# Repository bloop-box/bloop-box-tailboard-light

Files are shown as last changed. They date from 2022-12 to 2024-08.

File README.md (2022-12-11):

# Bloop Box Tailboard Light



Tailboard 3D Render

[Documentation](https://bloop-box.github.io/bloop-box-tailboard-light)

The board is designed using KiCAD 6 with production and assembly by JLCPCB in mind. All parts are selected to be
available from JLCPCB. At the time of writing as many parts as possible are used from their basic library.

- USB-C Power Input
- 5V only
- Two buttons connected to the Raspberry Pi, per default used for volume control
- Three LEDs 
  - One to show status of power supply
  - Two can be remote-controlled by Raspberry Pi through the Mainboard

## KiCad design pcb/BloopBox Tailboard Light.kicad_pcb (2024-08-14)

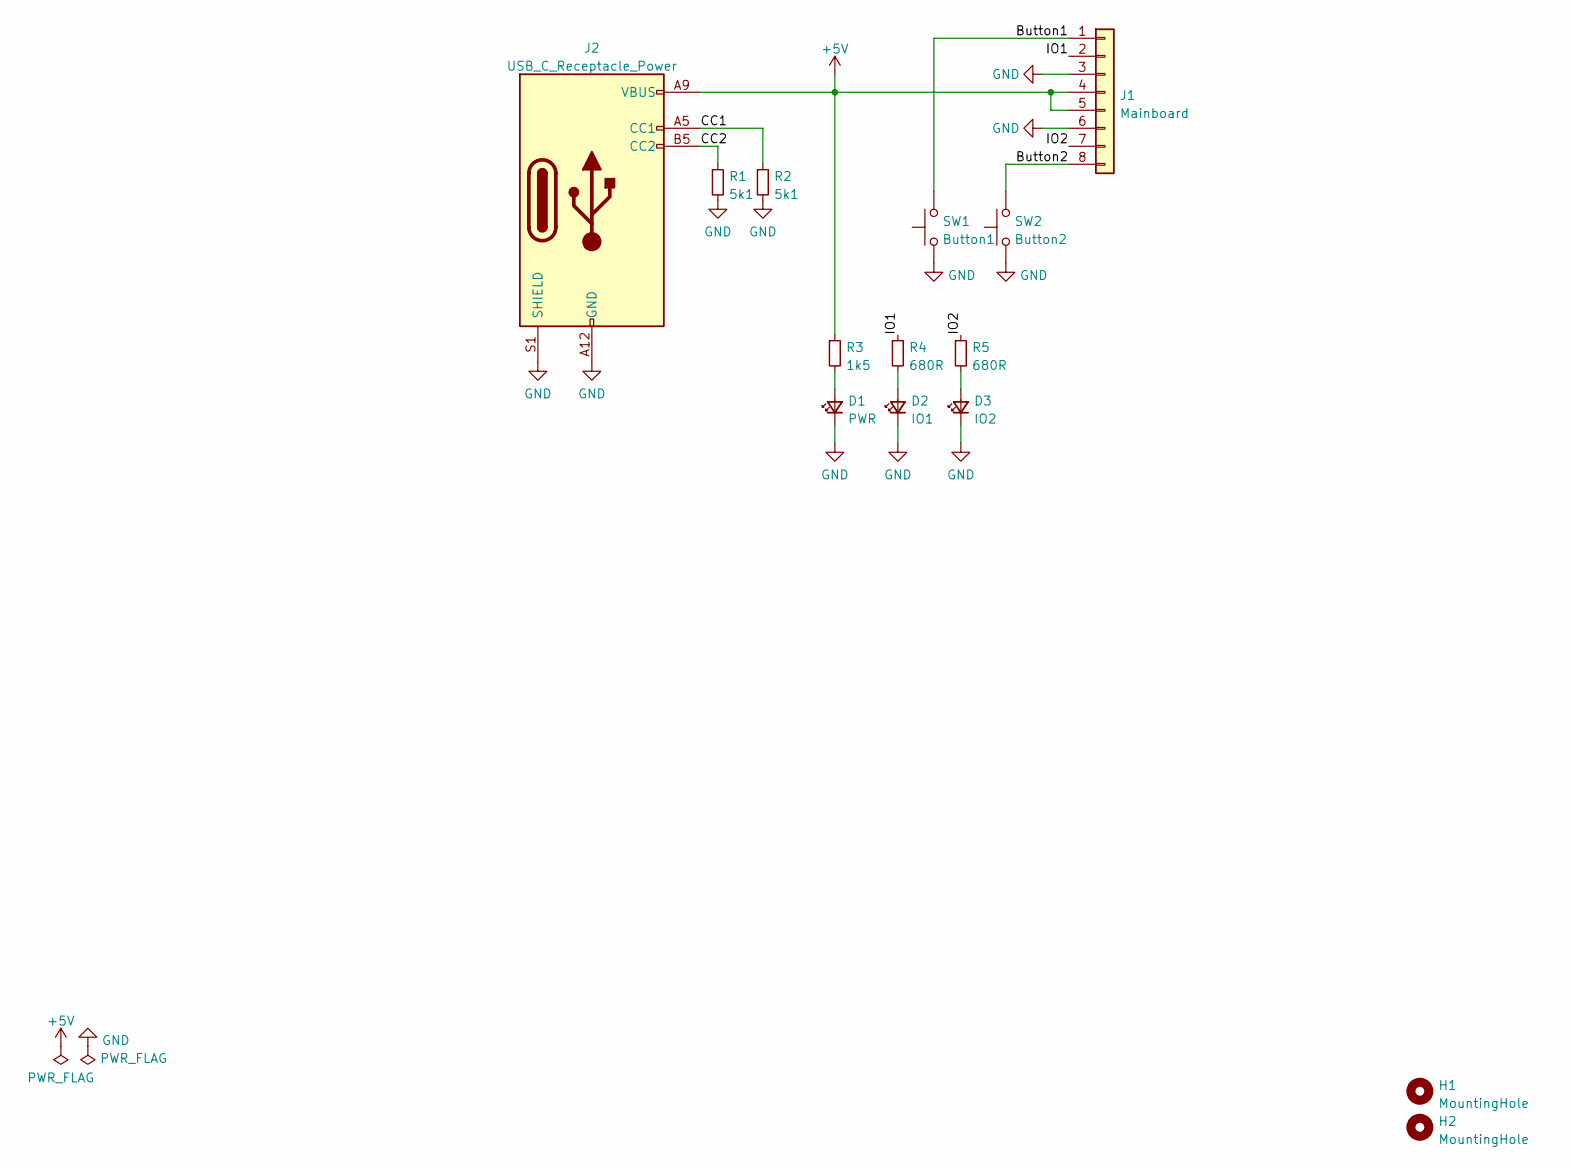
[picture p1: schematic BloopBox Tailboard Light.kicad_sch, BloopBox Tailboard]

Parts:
D1: PWR; LED_0603_1608Metric; LCSC C72038
D2: IO1; LED_0603_1608Metric; LCSC C72038
D3: IO2; LED_0603_1608Metric; LCSC C72038
H1, H2: MountingHole; MountingHole_3.2mm_M3
J1: Mainboard; JST_PH_S8B-PH-K_1x08_P2.00mm_Horizontal; LCSC C20598766
J2: USB_C_Receptacle_Power; GCT_USB4125-GF-A_REVA2; LCSC C283540
R1, R2: 5k1; R_0603_1608Metric; LCSC C23186
R3: 1k5; R_0603_1608Metric; LCSC C22843
R4, R5: 680R; R_0603_1608Metric; LCSC C23228
SW1: Button1; SW_Tactile_SPST_Angled_PTS645Vx83-2LFS; LCSC C338650
SW2: Button2; SW_Tactile_SPST_Angled_PTS645Vx83-2LFS; LCSC C338650

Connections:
+5V: J1.4, J1.5, J2.A9 (VBUS), J2.B9 (VBUS), R3.1
/Button1: J1.1, SW1.2
/Button2: J1.8, SW2.2
/CC1: J2.A5 (CC1), R2.1
/CC2: J2.B5 (CC2), R1.1
/IO1: J1.2, R4.1
/IO2: J1.7, R5.1
GND: D1.1 (K), D2.1 (K), D3.1 (K), J1.3, J1.6, J2.A12 (GND), J2.B12 (GND), J2.S1 (SHIELD), R1.2, R2.2, SW1.1, SW2.1
unnamed: D1.2 (A), R3.2
unnamed: D2.2 (A), R4.2
unnamed: D3.2 (A), R5.2

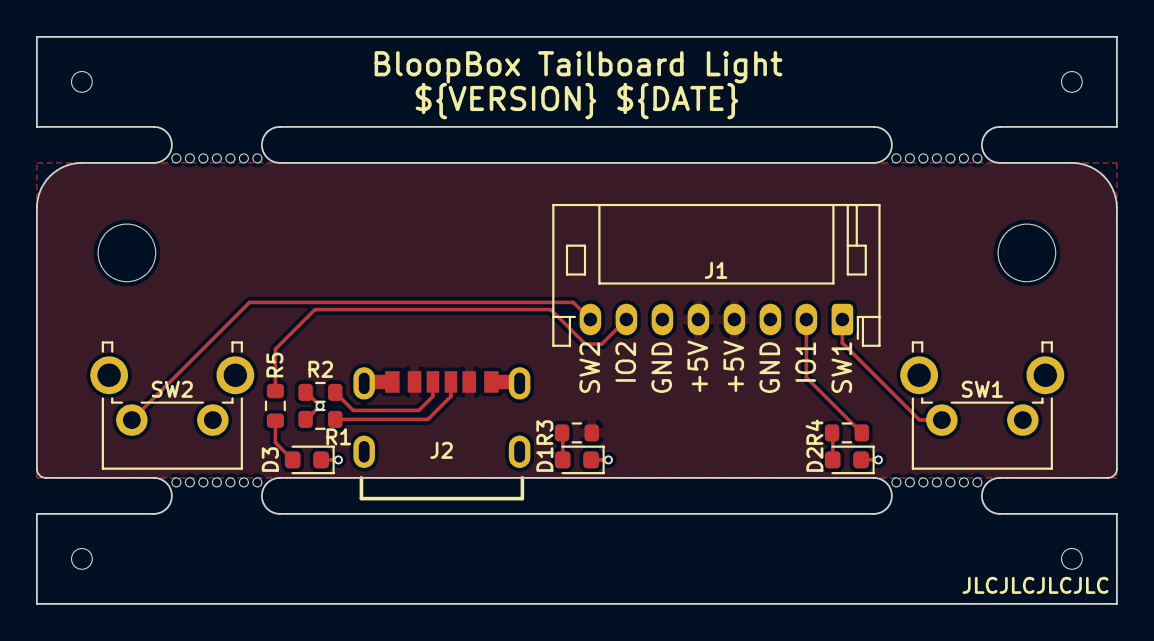
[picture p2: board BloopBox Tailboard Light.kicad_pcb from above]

Board: 2 copper layers, 60.0 x 31.5 mm, 18 parts (0 on the bottom side), 11 nets.

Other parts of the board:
mouse-bite-2mm-slot, mouse-bite-2mm-slot#2, mouse-bite-2mm-slot#3, mouse-bite-2mm-slot#4: VAL**; mouse-bite-2x5mm-slot-onesided

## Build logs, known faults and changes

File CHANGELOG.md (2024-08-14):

# Changelog

## [1.0.1](https://github.com/bloop-box/bloop-box-tailboard-light/compare/v1.0.0...v1.0.1) (2024-08-14)

### Bug Fixes

* part number for connector ([f40f8fa](https://github.com/bloop-box/bloop-box-tailboard-light/commit/f40f8fac28fb2f19ac4a79f4a39b4e0c32ab63a6))

## 1.0.0 (2022-12-11)

### ⚠ BREAKING CHANGES

* remove Power Delivery circuitry

### Features

* add and use versioning variables ([50b8ece](https://github.com/bloop-box/bloop-box-tailboard-light/commit/50b8eceeff82ba3242f2a5cd8d48997ad7749272))
* remove active circuitry from PCB ([d7ef60c](https://github.com/bloop-box/bloop-box-tailboard-light/commit/d7ef60c10efd3a18d48817f71b5ccd0a2888105a))
* remove active circuitry from schematics ([2085aa9](https://github.com/bloop-box/bloop-box-tailboard-light/commit/2085aa945b19bda381363235986c2ed81373c2ce))
* split tailboard into standalone repository ([192a561](https://github.com/bloop-box/bloop-box-tailboard-light/commit/192a5616ad0d687bc7e60cdefae15836de21bafe))

### Bug Fixes

* add missing LCSC part numbers ([aee9bbc](https://github.com/bloop-box/bloop-box-tailboard-light/commit/aee9bbc0874995dc930b6d6546f51aa283abd91d))
* change resistors to 0603 footptint ([109445c](https://github.com/bloop-box/bloop-box-tailboard-light/commit/109445c99ef60ce75f028571bfc1680613da04f6))
* remove Power Delivery circuitry ([44b3360](https://github.com/bloop-box/bloop-box-tailboard-light/commit/44b3360d34a09fa9a17619a7a237e2e1e54ea48a))
* remove unused net ([4403395](https://github.com/bloop-box/bloop-box-tailboard-light/commit/4403395e9e3cf90e65f822cdf2325b3c72bc3461))

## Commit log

2022-12-11 chore: fork Tailboard Repository
    Fork of BloopBox Tailboard for the light version
    [BloopBox Tailboard Light.kicad_pcb, BloopBox Tailboard Light.kicad_sch]
2022-12-11 feat: remove active circuitry from schematics
    Removing all active circuitry from the light-version of the Tailboard
    [BloopBox Tailboard Light.kicad_sch, buck.kicad_sch, inputselect.kicad_sch]
2022-12-11 feat: remove active circuitry from PCB
    [BloopBox Tailboard Light.kicad_pcb, BloopBox Tailboard Light.kicad_sch]
2022-12-11 fix: change resistors to 0603 footptint
    Changing the resistor footprints to 0603 to make hand-soldering easier, since this board does not have the size restraints of the full version of the Tailboard
    [BloopBox Tailboard Light.kicad_pcb, BloopBox Tailboard Light.kicad_sch]
2022-12-11 fix: remove unused net
    [BloopBox Tailboard Light.kicad_sch]
2024-08-14 chore: update to KiCad 8
    [BloopBox Tailboard Light.kicad_pcb, BloopBox Tailboard Light.kicad_sch]
2024-08-14 fix: part number for connector
    [BloopBox Tailboard Light.kicad_pcb, BloopBox Tailboard Light.kicad_sch]
